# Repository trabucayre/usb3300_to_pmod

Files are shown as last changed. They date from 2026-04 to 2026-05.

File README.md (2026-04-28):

# Waveshare USB3300 to dual PMOD PCB adapter

This repository is dedicated to a PCB adapter for the
[Waveshare USB3300 USB HS Board](https://www.waveshare.com/wiki/USB3300_USB_HS_Board).

The Waveshare module exposes the **USB3300 ULPI** interface on a 2x10 2.54 mm
header. Wiring this header to an FPGA board with loose jumpers can easily cause
signal integrity issues, especially with the 60 MHz `CLKOUT` signal and the
8-bit ULPI data bus.

This adapter converts the Waveshare 2x10 header to two standard 2x6 PMOD-style
connectors:

- `J3` carries the 8-bit ULPI data bus.
- `J2` carries the ULPI control signals, clock and reset.
- `J4` is the 2x10 connector for the Waveshare USB3300 board.
- `J1` exposes `+5V` and `GND`.

The board is passive: it does not include level shifters, buffers or regulators.
The FPGA board must be compatible with 3.3 V I/O for the ULPI signals.

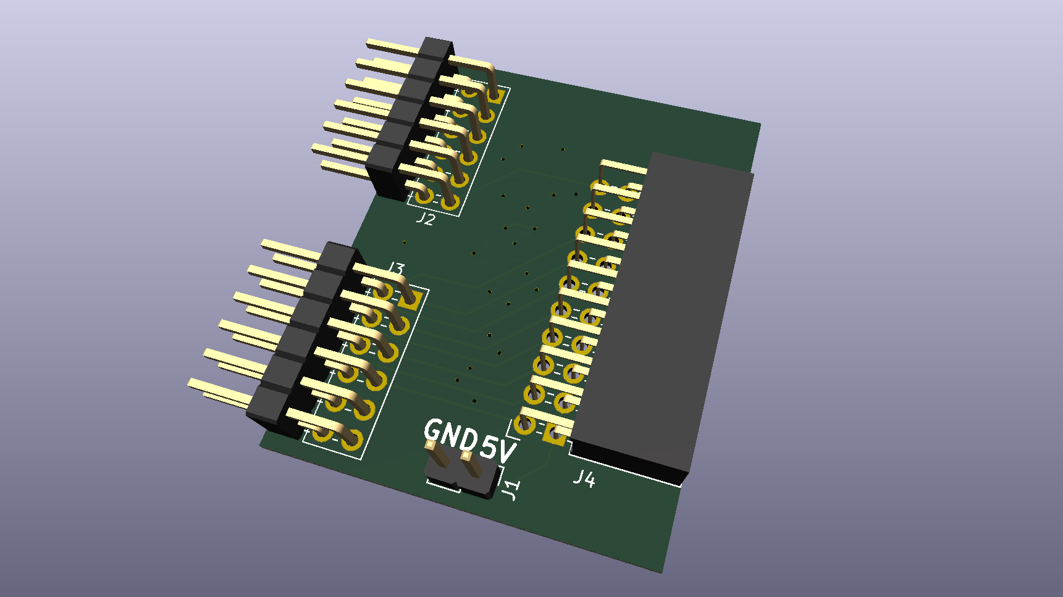
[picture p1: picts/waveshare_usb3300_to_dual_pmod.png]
waveshare_usb3300_to_dual_pmod


## Connector mapping

The PMOD connectors are dual-row 2x6 headers. Pins `1` to `6` are on the first
row, and pins `7` to `12` are on the second row.

### PMOD J3: ULPI data bus

| Row 1 pin | Signal  | Row 2 pin | Signal  |
| --- | --- | --- | --- |
| 1 | `DATA6` |  7 | `DATA7` |
| 2 | `DATA4` |  8 | `DATA5` |
| 3 | `DATA2` |  9 | `DATA3` |
| 4 | `DATA0` | 10 | `DATA1` |
| 5 | `GND` | 11 | `GND` |
| 6 | `+3.3V` | 12 | `+3.3V` |

### PMOD J2: ULPI control

| Row 1 pin | Signal  | Row 2 pin |  Signal  |
| --- | --- | --- | --- |
| 1 | `STP` |  7 | NC |
| 2 | `NXT` |  8 | NC |
| 3 | NC |  9 | `CLKOUT` |
| 4 | `DIR` | 10 | `RESET`  |
| 5 | `GND` | 11 | `GND` |
| 6 | `+3.3V` | 12 | `+3.3V`  |

### Waveshare USB3300 header J4

| J4 pin | Signal | J4 pin | Signal  |
| --- | --- | --- | --- |
|  1 | `+5V` |  2 | `DATA0` |
|  3 | `+5V` |  4 | `DATA1` |
|  5 | NC |  6 | `DATA2` |
|  7 | `RESET`  |  8 | `DATA3` |
|  9 | `CLKOUT` | 10 | `DATA4` |
| 11 | `DIR` | 12 | `DATA5` |
| 13 | `NXT` | 14 | `DATA6` |
| 15 | `STP` | 16 | `DATA7` |
| 17 | `GND` | 18 | `GND` |
| 19 | `+3.3V`  | 20 | `+3.3V` |

## Electrical notes

- The adapter routes the ULPI bus directly between the Waveshare board and the
  PMOD connectors.
- `+3.3V` is distributed to the PMOD power pins and to the Waveshare header.
- `+5V` is routed to the Waveshare header and to the auxiliary `J1` header (Only
  required in device mode).
- Use short PMOD connections and keep both PMOD connectors attached to the same
  FPGA bank when possible.
- Verify the target board pinout before connecting. Not all 2x6 connectors use
  the same PMOD orientation or power-pin placement.

## Examples

The `examples` directory contains modified LiteX targets using the USB3300 as a
USB CDC ACM UART.

### Prerequisites

Using CDC ACM requires [amaranth](https://github.com/amaranth-lang/amaranth),
[Luna](https://github.com/greatscottgadgets/luna) and
[LiteX](https://github.com/enjoy-digital/litex).

**amaranth**

```bash
git clone https://github.com/amaranth-lang/amaranth.git
cd amaranth
# v0.5.8 is required by Luna
git checkout v0.5.8
pip3 install --user --break-system-packages -e .
cd ..
```

**Luna**

```bash
git clone https://github.com/greatscottgadgets/luna.git
cd luna
git checkout 0.2.3
# A commit has introduced a regression and must be reverted
# (https://github.com/greatscottgadgets/luna/issues/280)
git revert --no-edit cf6abaae922bd3f04ca6118f0a7d26b768859d28
pip3 install --user --break-system-packages -e .
cd ..
```

**LiteX**

This step is well documented in the
[official page](https://github.com/enjoy-digital/litex/#quick-start-guide)

### Build

To build a gateware image, use:

```bash
cd examples
./board_name.py --uart-name usb_acm --build --load
```

Where `board_name.py` may be:

- `digilent_arty_s7.py`

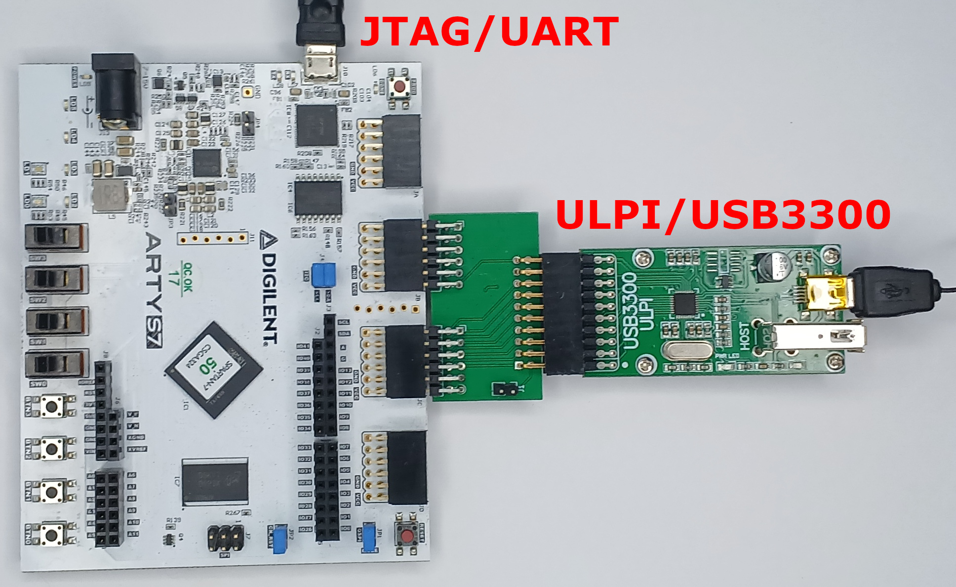
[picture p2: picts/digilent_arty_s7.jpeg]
digilent_arty_s7
  
- `sipeed_tang_mega_138k.py`

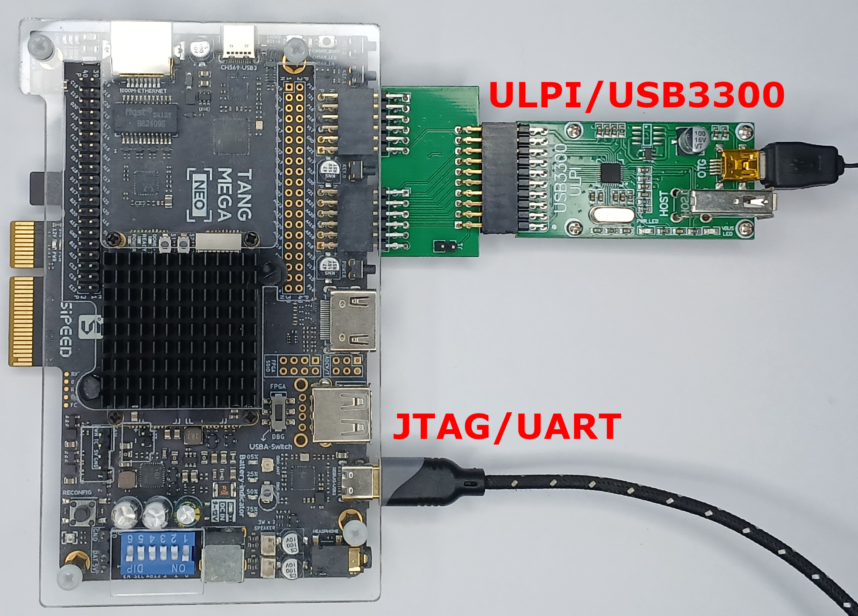
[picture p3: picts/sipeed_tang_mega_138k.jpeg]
sipeed_tang_mega_138k
  
- `arrow_axe5000.py`
  Requires the [Ziggy Bridge MKR](https://github.com/steieio/ziggybridge-mkr)

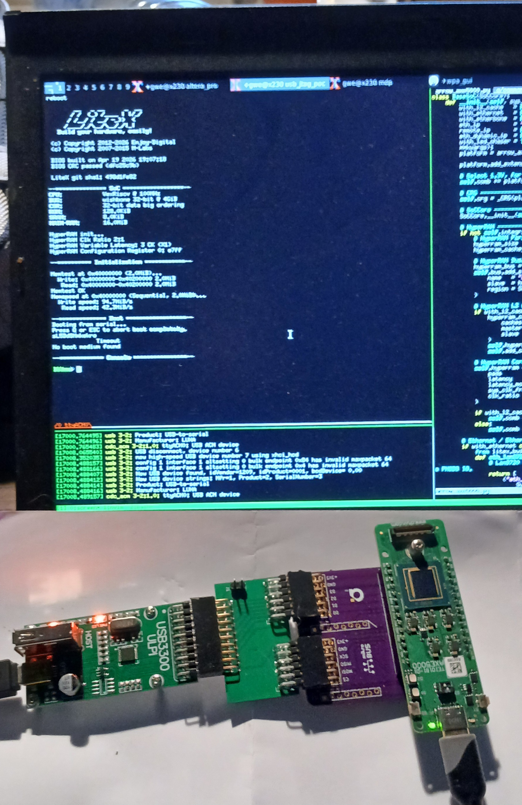
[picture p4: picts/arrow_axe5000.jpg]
arrow_axe5000
  

## Contact

E-mail: Gwenhael Goavec-Merou <gwenhael.goavec-merou@trabucayre.com></br>
Copyright (C) <b>2026</b></br>

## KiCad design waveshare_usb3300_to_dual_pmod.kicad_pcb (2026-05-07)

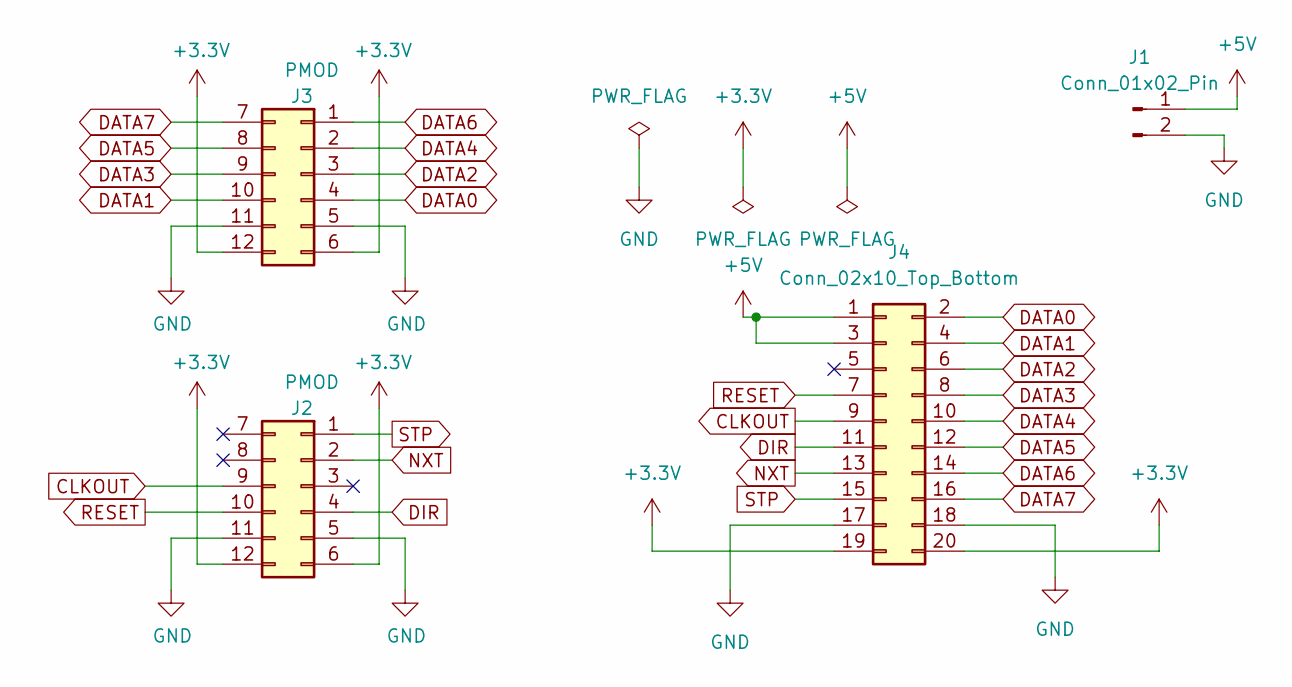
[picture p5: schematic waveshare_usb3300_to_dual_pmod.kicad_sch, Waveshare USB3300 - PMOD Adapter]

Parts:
J1: Conn_01x02_Pin; PinHeader_1x02_P2.54mm_Vertical
J2, J3: PMOD; PMODHeader_2x06_P2.54mm_Horizontal
J4: Conn_02x10_Top_Bottom; PinSocket_2x10_P2.54mm_Horizontal

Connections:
+3.3V: J2.6, J2.12, J3.6, J3.12, J4.19, J4.20
+5V: J1.1, J4.1, J4.3
CLKOUT: J2.9, J4.9
DATA0: J3.4, J4.2
DATA1: J3.10, J4.4
DATA2: J3.3, J4.6
DATA3: J3.9, J4.8
DATA4: J3.2, J4.10
DATA5: J3.8, J4.12
DATA6: J3.1, J4.14
DATA7: J3.7, J4.16
DIR: J2.4, J4.11
GND: J1.2, J2.5, J2.11, J3.5, J3.11, J4.17, J4.18
NXT: J2.2, J4.13
RESET: J2.10, J4.7
STP: J2.1, J4.15

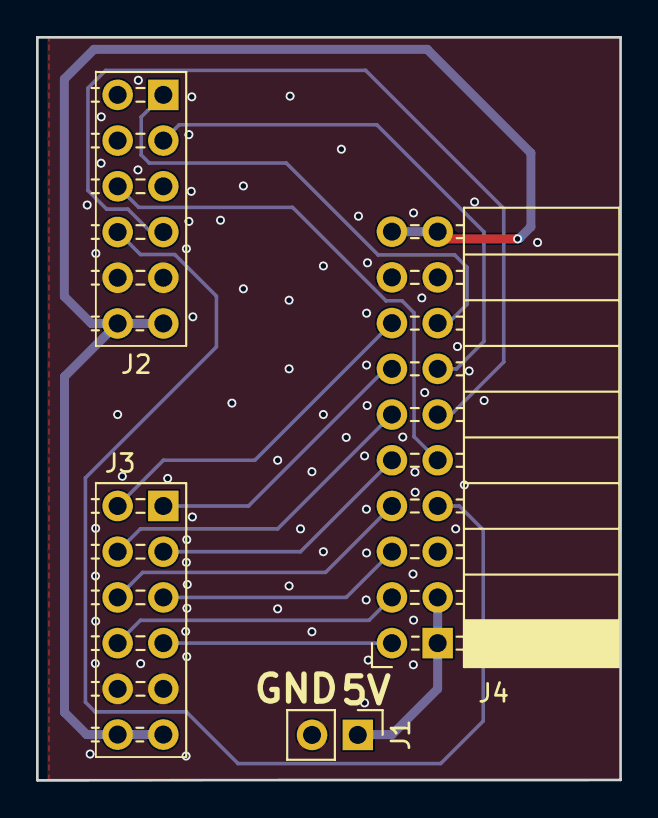
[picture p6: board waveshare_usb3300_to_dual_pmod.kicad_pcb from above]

Board: 2 copper layers, 32.4 x 41.3 mm, 4 parts (0 on the bottom side), 16 nets.

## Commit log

2026-04-27 import kicad project
    [waveshare_usb3300_to_dual_pmod.kicad_pcb, waveshare_usb3300_to_dual_pmod.kicad_sch]
2026-04-27 lib/pkl/pinsocket_2.54mm_horizontal: custom J4/usb3300 footprint
2026-04-27 waveshare_usb3300_to_dual_pmod: changed j4 footprint, resize PCB
    [waveshare_usb3300_to_dual_pmod.kicad_pcb, waveshare_usb3300_to_dual_pmod.kicad_sch]
2026-05-05 waveshare_usb3300_to_dual_pmod.kicad_pcb: reworks GND (thanks Goran!)
    [waveshare_usb3300_to_dual_pmod.kicad_pcb]
2026-05-07 waveshare_usb3300_to_dual_pmod.kicad_pcb: updates clock routing (thanks Goran)
    [waveshare_usb3300_to_dual_pmod.kicad_pcb]

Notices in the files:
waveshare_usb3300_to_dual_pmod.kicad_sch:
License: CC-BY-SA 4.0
